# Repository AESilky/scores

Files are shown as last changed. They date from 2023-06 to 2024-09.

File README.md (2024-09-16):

# Score Board

Two team score board w/remote for use in the yard when playing different games
like ladder-ball, cornhole, horseshoes, basketball, etc.

Options for two display types:

1. 2 Digits each for Team-A, Team-B, and a third for Period, Time, etc., and 4 indicators for each team.
2. 2 Linear rows of 24 dots each (for Team-A and Team-B), and 4 indicators for each team.

The Digits type is a typical score board that you would use for baseball,
basketball, football, etc. The Linear display is appropriate for games that
go from 0 to some number of points (maximum of 24), like cornhole, ladderball,
horseshoes, etc.

It uses either a remote or switch banks to control the score. It can use the
remote alone, or with a switch bank, or with two switch banks (without the remote).
The switch banks have either 4 or 6 switches. When using two switch banks, there
is a bank for each team that allow increasing/decreasing the score, resetting to
a lower score (typically 11) and to zero.

The board has a Zigby receiver for non line of sight, communication (though not
yet supported).

The board uses multiplexed 7 segment LED displays to provide a two team/player
two digit score, plus a two digit number that can count periods, innings,
quarters, etc., or can count down/up time. There are four LEDs under the score
for each side that can be used to indicate timeouts left, substitutions made,
etc.

The linear display is also multiplexed LEDs, using the segment drives.

The board also has a OLED display panel (SPI) that can also display the score (intended
for the back side to assist a scorekeeper), as well as for use for setup.

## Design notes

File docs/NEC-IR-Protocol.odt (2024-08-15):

The NEC IR transmission protocol uses pulse distance encoding of the message bits. Each pulse burst (mark – RC transmitter ON) is 562.5µs in length, at a carrier frequency of 38kHz (26.3µs). Logical bits are transmitted as follows:

- Logical '0' – a 562.5µs pulse burst followed by a 562.5µs space, with a total transmit time of 1.125ms
- Logical '1' – a 562.5µs pulse burst followed by a 1.6875ms space, with a total transmit time of 2.25ms

When a key is pressed on the remote controller, the message transmitted consists of the following, in order:

- a 9ms leading pulse burst (16 times the pulse burst length used for a logical data bit)
- a 4.5ms space
- the 8-bit address for the receiving device
- the 8-bit logical inverse of the address
- the 8-bit command
- the 8-bit logical inverse of the command
- a final 562.5µs pulse burst to signify the end of message transmission.

The four bytes of data bits are each sent least significant bit first. Figure 1 illustrates the format of an NEC IR transmission frame, for an address of 00h (00000000b) and a command of ADh (10101101b).

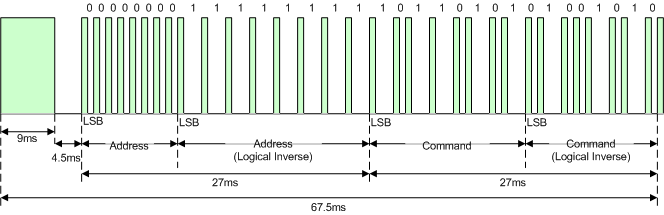
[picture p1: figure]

Figure 1. Example message frame using the NEC IR transmission protocol.

Notice from Figure 1 that it takes:

- 27ms to transmit both the 16 bits for the address (address + inverse) and the 16 bits for the command (command + inverse). This comes from each of the 16 bit blocks ultimately containing eight '0's and eight '1's - giving (8 * 1.125ms) + (8 * 2.25ms).
- 67.5ms to fully transmit the message frame (discounting the final 562.5µs pulse burst that signifies the end of message).

## Repeat Codes

If the key on the remote controller is kept depressed, a repeat code will be issued, typically around 40ms after the pulse burst that signified the end of the message. A repeat code will continue to be sent out at 108ms intervals, until the key is finally released. The repeat code consists of the following, in order:

- a 9ms leading pulse burst
- a 2.25ms space
- a 562.5µs pulse burst to mark the end of the space (and hence end of the transmitted repeat code).

Figure 2 illustrates the transmission of two repeat codes after an initial message frame is sent.

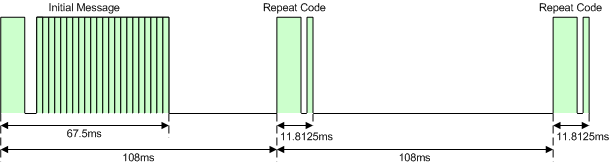
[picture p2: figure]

Figure 2. Example repeat codes sent for a key held down on the transmitting remote controller.

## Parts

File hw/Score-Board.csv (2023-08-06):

Source: | C:\Users\aesil\proj\scores\scores\hw\Score-Board.kicad_sch
Date: | 8/5/2023 7:06:16 PM
Tool: | Eeschema 7.0.2
Generator: | C:\Program Files\KiCad\7.0\bin\scripting\plugins/bom_csv_grouped_by_value_with_fp.py
Component Count: | 95
Ref | Qnty | Value | Cmp name | Footprint | Description | Vendor | DNP
BZ1 | 1 | Buzzer | Buzzer | Buzzer_Beeper:Buzzer_12x9.5RM7.6 | Buzzer, polarized
C1 | 1 | 10uF | C_Polarized_US | Capacitor_THT:CP_Radial_D8.0mm_P3.50mm | Polarized capacitor, US symbol
C2, C3 | 2 | 1.0uF | C | Capacitor_THT:CP_Radial_D5.0mm_P2.00mm | Unpolarized capacitor
C4, C5 | 2 | 0.1uF | C_Small | Capacitor_THT:C_Disc_D5.0mm_W2.5mm_P2.50mm | Unpolarized capacitor, small symbol
Conn1 | 1 | Conn_02x09_Odd_Even | Conn_02x09_Odd_Even | Connector_PinHeader_2.54mm:PinHeader_2x09_P2.54mm_Vertical | Generic connector, double row, 02x09, odd/even pin numbering scheme (row 1 odd numbers, row 2 even numbers), script generated (kicad-library-utils/schlib/autogen/connector/)
D1 | 1 | 1N4004 | 1N4004 | Diode_THT:D_DO-41_SOD81_P10.16mm_Horizontal | 400V 1A General Purpose Rectifier Diode, DO-41
D2, D4 | 2 | D_Schottky_PP | Schottky_Diode_PWR_Protect_AES | Diode_THT:D_DO-35_SOD27_P10.16mm_Horizontal | Schottky diode - Small Reverse Power Protection
D3 | 1 | D_Schottky | D_Schottky | Diode_THT:D_DO-35_SOD27_P10.16mm_Horizontal | Schottky diode
H1, H2, H3, H4, H5, H6 | 6 | MountingHole | MountingHole | MountingHole:MountingHole_3.2mm_M3 | Mounting Hole without connection
IR1, IR2 | 2 | TSOP382xx | TSOP382xx | OptoDevice:Vishay_MINICAST-3Pin | Photo Modules for PCM Remote Control Systems
J1 | 1 | Barrel_Jack | Barrel_Jack | AES_Library:CUI_PJ-037B | DC Barrel Jack
J2 | 1 | Screw_Terminal_01x02 | Screw_Terminal_01x02 | TerminalBlock_Philmore:TerminalBlock_Philmore_TB132_1x02_P5.00mm_Horizontal | Generic screw terminal, single row, 01x02, script generated (kicad-library-utils/schlib/autogen/connector/)
J3 | 1 | SPI-Disp | Conn_01x07 | Connector_PinSocket_2.54mm:PinSocket_1x07_P2.54mm_Vertical | Generic connector, single row, 01x07, script generated (kicad-library-utils/schlib/autogen/connector/)
J4 | 1 | Conn_01x03 | Conn_01x03 | Connector_PinHeader_2.54mm:PinHeader_1x03_P2.54mm_Vertical | Generic connector, single row, 01x03, script generated (kicad-library-utils/schlib/autogen/connector/)
J5 | 1 | Conn_01x04 | Conn_01x04 | Connector_PinHeader_2.54mm:PinHeader_1x04_P2.54mm_Vertical | Generic connector, single row, 01x04, script generated (kicad-library-utils/schlib/autogen/connector/)
J6 | 1 | J-V3.3 | Conn_01x02 | Connector_PinHeader_2.54mm:PinHeader_1x02_P2.54mm_Vertical | Generic connector, single row, 01x02, script generated (kicad-library-utils/schlib/autogen/connector/)
J7 | 1 | J-V12 | Conn_01x02 | Connector_PinHeader_2.54mm:PinHeader_1x02_P2.54mm_Vertical | Generic connector, single row, 01x02, script generated (kicad-library-utils/schlib/autogen/connector/)
J8 | 1 | J-VSYS | Conn_01x02 | Connector_PinHeader_2.54mm:PinHeader_1x02_P2.54mm_Vertical | Generic connector, single row, 01x02, script generated (kicad-library-utils/schlib/autogen/connector/)
LED1 | 1 | PWR | LED | LED_THT:LED_D5.0mm | Light emitting diode
LED2 | 1 | ZBRUN | LED | LED_THT:LED_D5.0mm | Light emitting diode
LED3 | 1 | ZBNWRK | LED | LED_THT:LED_D5.0mm | Light emitting diode
Q1, Q2, Q3, Q4, Q5, Q6, Q7, Q15, Q16, Q17, Q18, Q19, Q20, Q21, Q22 | 15 | 2N3904 | 2N3904 | Package_TO_SOT_THT:TO-92_Inline | 0.2A Ic, 40V Vce, Small Signal NPN Transistor, TO-92
Q8, Q9, Q10, Q11, Q12, Q13, Q14 | 7 | 2N3905 | 2N3905 | Package_TO_SOT_THT:TO-92_Inline | -0.2A Ic, -40V Vce, Small Signal PNP Transistor, TO-92
R1, R2, R3, R4, R5 | 5 | 150 | R_Small_US | Resistor_THT:R_Axial_DIN0207_L6.3mm_D2.5mm_P10.16mm_Horizontal | Resistor, small US symbol
R6, R8, R10, R12, R14, R16, R18 | 7 | 1k | R_Small_US | Resistor_THT:R_Axial_DIN0207_L6.3mm_D2.5mm_P10.16mm_Horizontal | Resistor, small US symbol
R7, R9, R11, R13, R15, R17, R19 | 7 | 270 | R_Small_US | Resistor_THT:R_Axial_DIN0207_L6.3mm_D2.5mm_P10.16mm_Horizontal | Resistor, small US symbol
R20, R33, R34, R39, R40, R41, R42, R43 | 8 | 47 | R_Small_US | Resistor_THT:R_Axial_DIN0207_L6.3mm_D2.5mm_P10.16mm_Horizontal | Resistor, small US symbol
R21, R22, R23, R24, R25, R26, R27, R28 | 8 | 10k | R_Small_US | Resistor_THT:R_Axial_DIN0207_L6.3mm_D2.5mm_P10.16mm_Horizontal | Resistor, small US symbol
SD1 | 1 | MicroSD-Socket | Micro_SD_Card_Det1 | AES_Library:SDCard-GCT_MEM2075-00-140-01-A | Micro SD Card Socket with one card detection pin
SW1 | 1 | RESET | SW_Push | AES_Library:SW_TL1100F160Q | Push button switch, generic, two pins
SW2 | 1 | NETWORK | SW_Push | AES_Library:SW_TL1100F160Q | Push button switch, generic, two pins
SW3 | 1 | INPUT-SW | SW_Push | AES_Library:SW_TL1100F160Q | Push button switch, generic, two pins
TP1 | 1 | Conn_01x01 | Conn_01x01 | Connector_PinHeader_2.54mm:PinHeader_1x01_P2.54mm_Vertical | Generic connector, single row, 01x01, script generated (kicad-library-utils/schlib/autogen/connector/)
U1 | 1 | PicoW | PicoW | AES_Library:RPi_PicoW_SMD_TH
U2 | 1 | E18-MS1-PCB | E18-MS1-PCB | AES_Library:E18-MS1-PCB-AES | EBYTE ZigBee 3.0 E18 Command Module
U5 | 1 | MCP1702-5002E | MCP1700x-500xxTO | Package_TO_SOT_THT:TO-92_Inline | 250mA Low Quiscent Current LDO, 5.0V output, TO-92

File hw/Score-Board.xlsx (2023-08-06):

Source: | C:\Users\aesil\proj\scores\scores\hw\Score-Board.kicad_sch
Date: | 2023-08-05 19:06
Tool: | Eeschema 7.0.2
Generator: | C:\Program Files\KiCad\7.0\bin\scripting\plugins/bom_csv_grouped_by_value_with_fp.py
Component Count: | 95
Ref | Qnty | Value | Cmp name | Description | DNP
BZ1 | 1 | Buzzer | Buzzer | Buzzer, polarized
C1 | 1 | 10uF | C_Polarized_US | Polarized capacitor, US symbol
C2, C3 | 2 | 1.0uF | C | Unpolarized capacitor
C4, C5 | 2 | 0.1uF | C_Small | Unpolarized capacitor, small symbol
Conn1 | 1 | Conn_02x09_Odd_Even | Conn_02x09_Odd_Even | Generic connector, double row, 02x09, odd/even pin numbering
D1 | 1 | 1N4004 | 1N4004 | 400V 1A General Purpose Rectifier Diode, DO-41
D2, D4 | 2 | D_Schottky_PP | Schottky_Diode_PWR_Protect_AES | Schottky diode - Small Reverse Power Protection
D3 | 1 | D_Schottky | D_Schottky | Schottky diode
H1, H2, H3, H4, H5, H6 | 6 | MountingHole | MountingHole | Mounting Hole without connection
IR1, IR2 | 2 | TSOP382xx | TSOP382xx | Photo Modules for PCM Remote Control Systems
J1 | 1 | Barrel_Jack | Barrel_Jack | DC Barrel Jack
J2 | 1 | Screw_Terminal_01x02 | Screw_Terminal_01x02 | Generic screw terminal, single row, 01x02
J3 | 1 | SPI-Disp | Conn_01x07 | Generic connector, single row, 01x07
J4 | 1 | Conn_01x03 | Conn_01x03 | Generic connector, single row, 01x03
J5 | 1 | Conn_01x04 | Conn_01x04 | Generic connector, single row, 01x04
J6 | 1 | J-V3.3 | Conn_01x02 | Generic connector, single row, 01x02
J7 | 1 | J-V12 | Conn_01x02 | Generic connector, single row, 01x02
J8 | 1 | J-VSYS | Conn_01x02 | Generic connector, single row, 01x02
LED1 | 1 | PWR | LED | Light emitting diode
LED2 | 1 | ZBRUN | LED | Light emitting diode
LED3 | 1 | ZBNWRK | LED | Light emitting diode
Q1, Q2, Q3, Q4, Q5, Q6, Q7, Q15, Q16, Q17, Q18, Q19, Q20, Q21, Q22 | 15 | 2N3904 | 2N3904 | 0.2A Ic, 40V Vce, Small Signal NPN Transistor, TO-92
Q8, Q9, Q10, Q11, Q12, Q13, Q14 | 7 | 2N3905 | 2N3905 | -0.2A Ic, -40V Vce, Small Signal PNP Transistor, TO-92
R1, R2, R3, R4, R5 | 5 | 150 | R_Small_US | Resistor, small US symbol
R6, R8, R10, R12, R14, R16, R18 | 7 | 1k | R_Small_US | Resistor, small US symbol
R7, R9, R11, R13, R15, R17, R19 | 7 | 270 | R_Small_US | Resistor, small US symbol
R20, R33, R34, R39, R40, R41, R42, R43 | 8 | 47 | R_Small_US | Resistor, small US symbol
R21, R22, R23, R24, R25, R26, R27, R28 | 8 | 10k | R_Small_US | Resistor, small US symbol
SD1 | 1 | MicroSD-Socket | Micro_SD_Card_Det1 | Micro SD Card Socket with one card detection pin
SW1 | 1 | RESET | SW_Push | Push button switch, generic, two pins
SW2 | 1 | NETWORK | SW_Push | Push button switch, generic, two pins
SW3 | 1 | INPUT-SW | SW_Push | Push button switch, generic, two pins
TP1 | 1 | Conn_01x01 | Conn_01x01 | Generic connector, single row, 01x01
U1 | 1 | PicoW | PicoW
U2 | 1 | E18-MS1-PCB | E18-MS1-PCB | EBYTE ZigBee 3.0 E18 Command Module
U5 | 1 | MCP1702-5002E | MCP1700x-500xxTO | 250mA Low Quiscent Current LDO, 5.0V output, TO-92

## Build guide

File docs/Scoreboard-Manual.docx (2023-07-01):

Silky Portable Scoreboard w/Remote

Cover page
back

No page number

# About the Silky Scoreboard

The Silky Scoreboard w/Remote (SSwR) is a portable, two team/player scoreboard with an Infrared and radio (ZigBee) wireless remote. The scoreboard has multiple modes tailored to keeping score for a variety of common games.

First numbered even page

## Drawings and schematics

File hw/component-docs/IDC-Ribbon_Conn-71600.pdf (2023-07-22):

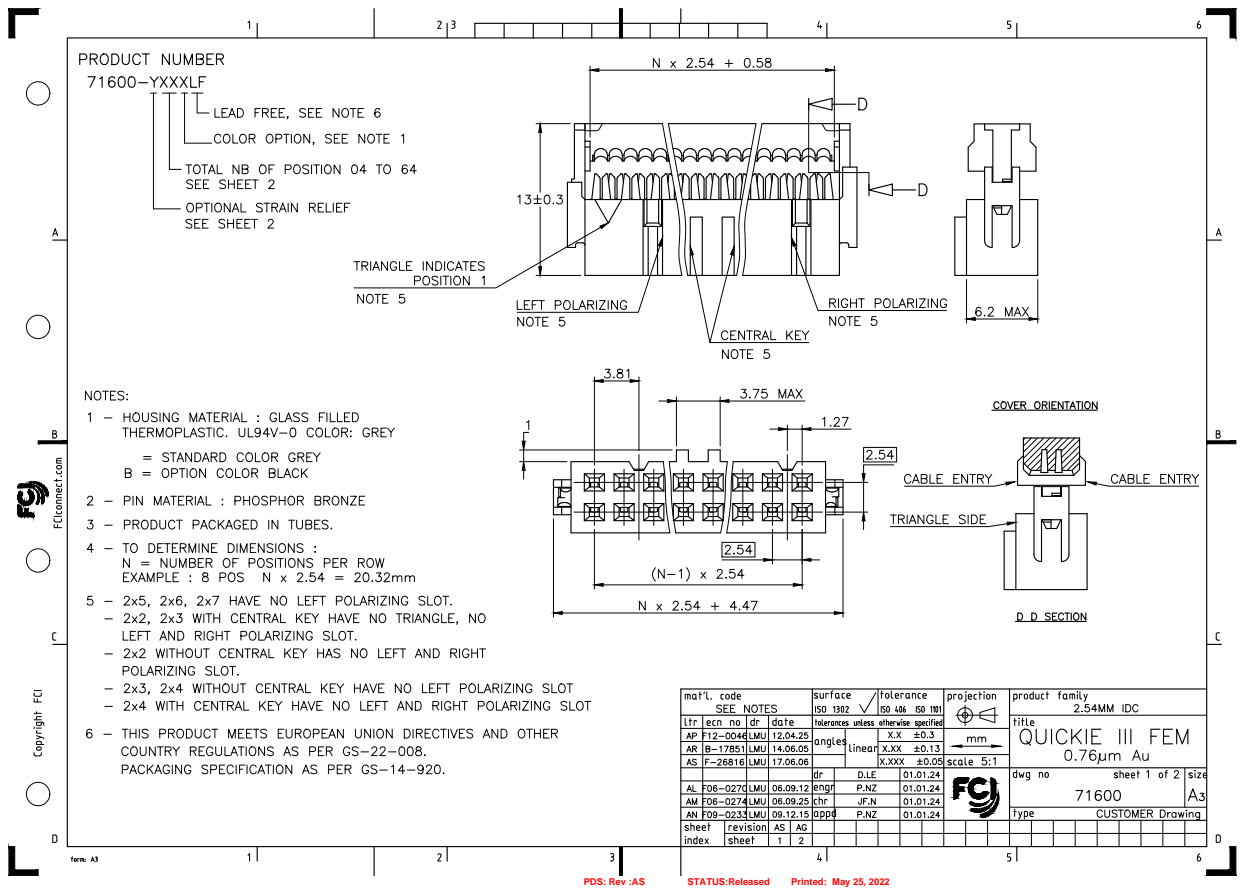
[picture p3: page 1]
PDS: Rev :AS; STATUS:Released; Printed: May 25, 2022

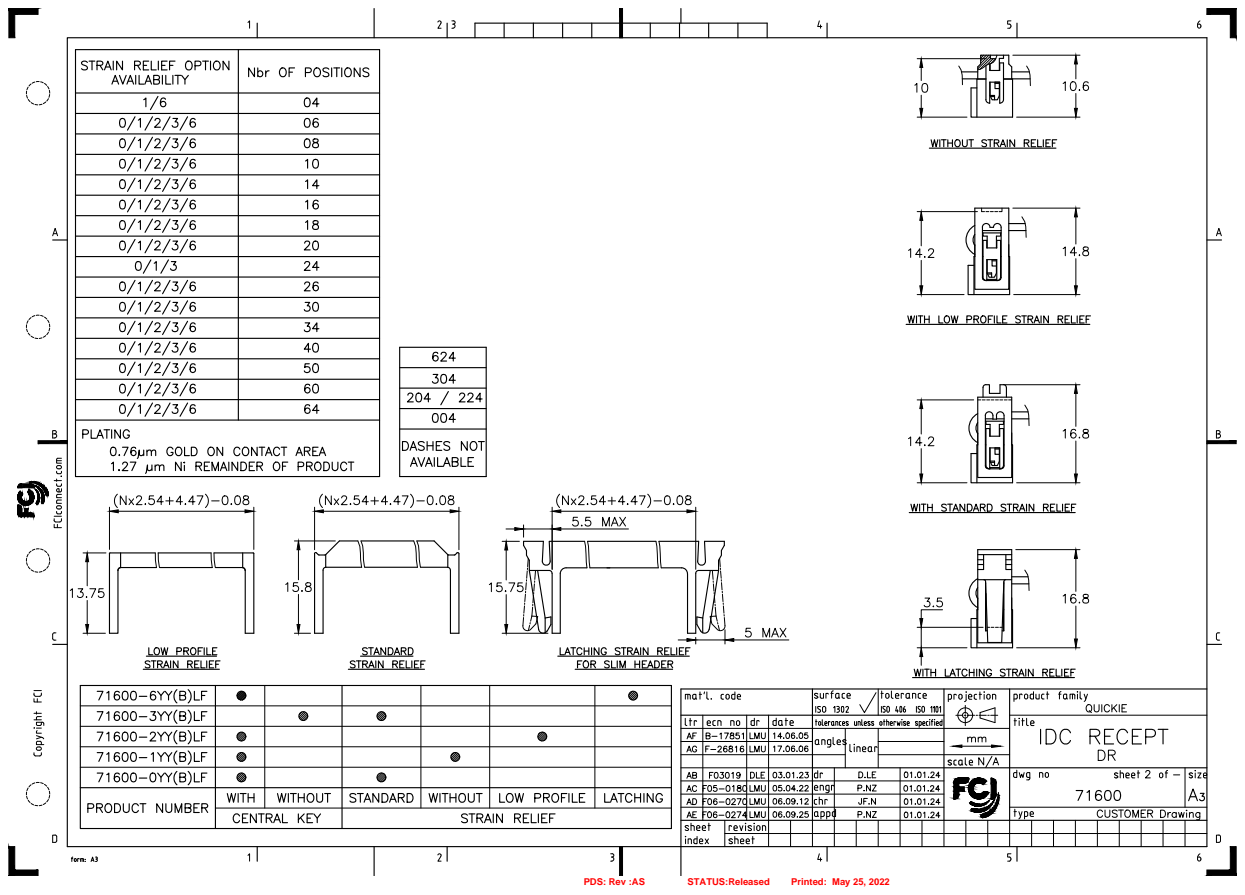
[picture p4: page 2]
PDS: Rev :AS; STATUS:Released; Printed: May 25, 2022

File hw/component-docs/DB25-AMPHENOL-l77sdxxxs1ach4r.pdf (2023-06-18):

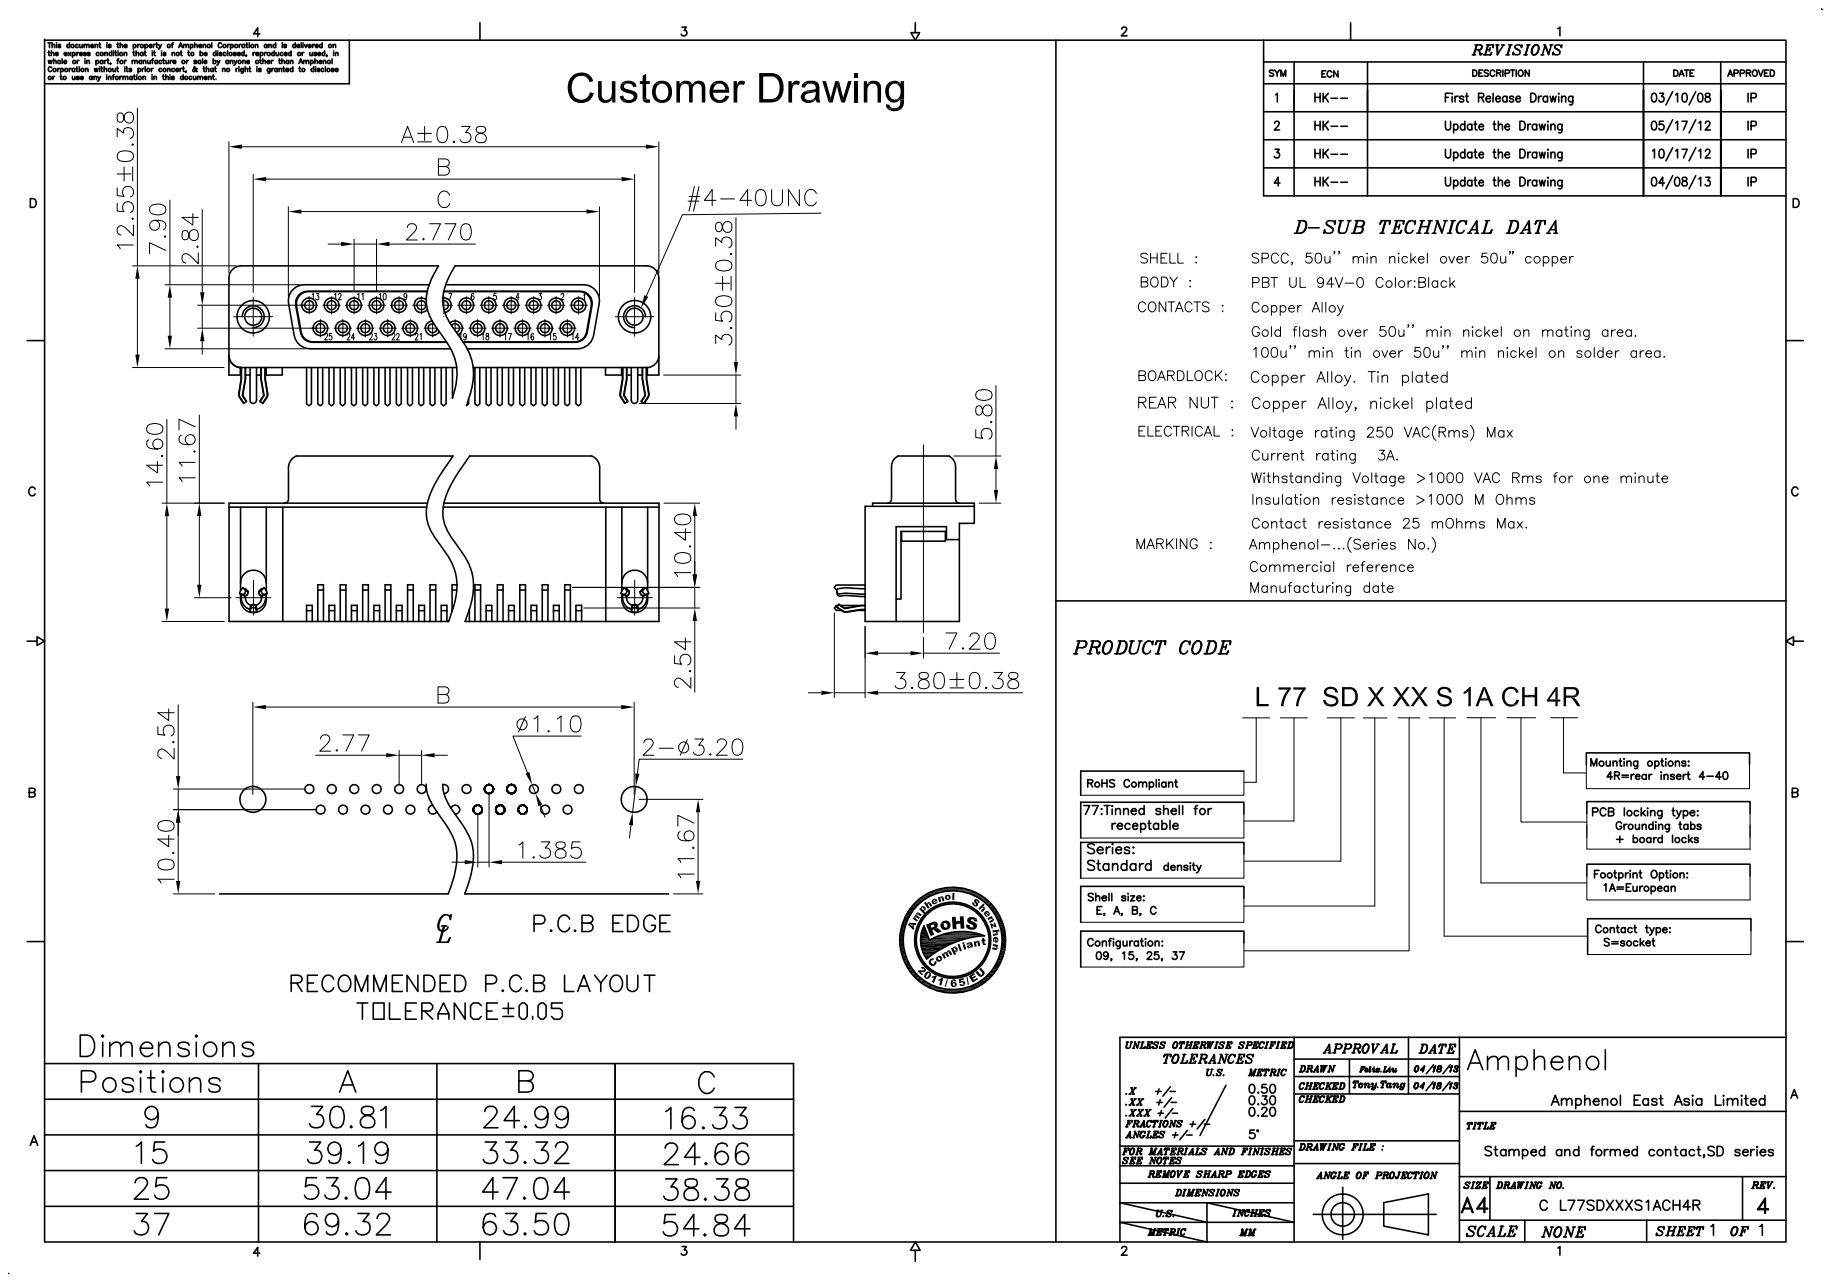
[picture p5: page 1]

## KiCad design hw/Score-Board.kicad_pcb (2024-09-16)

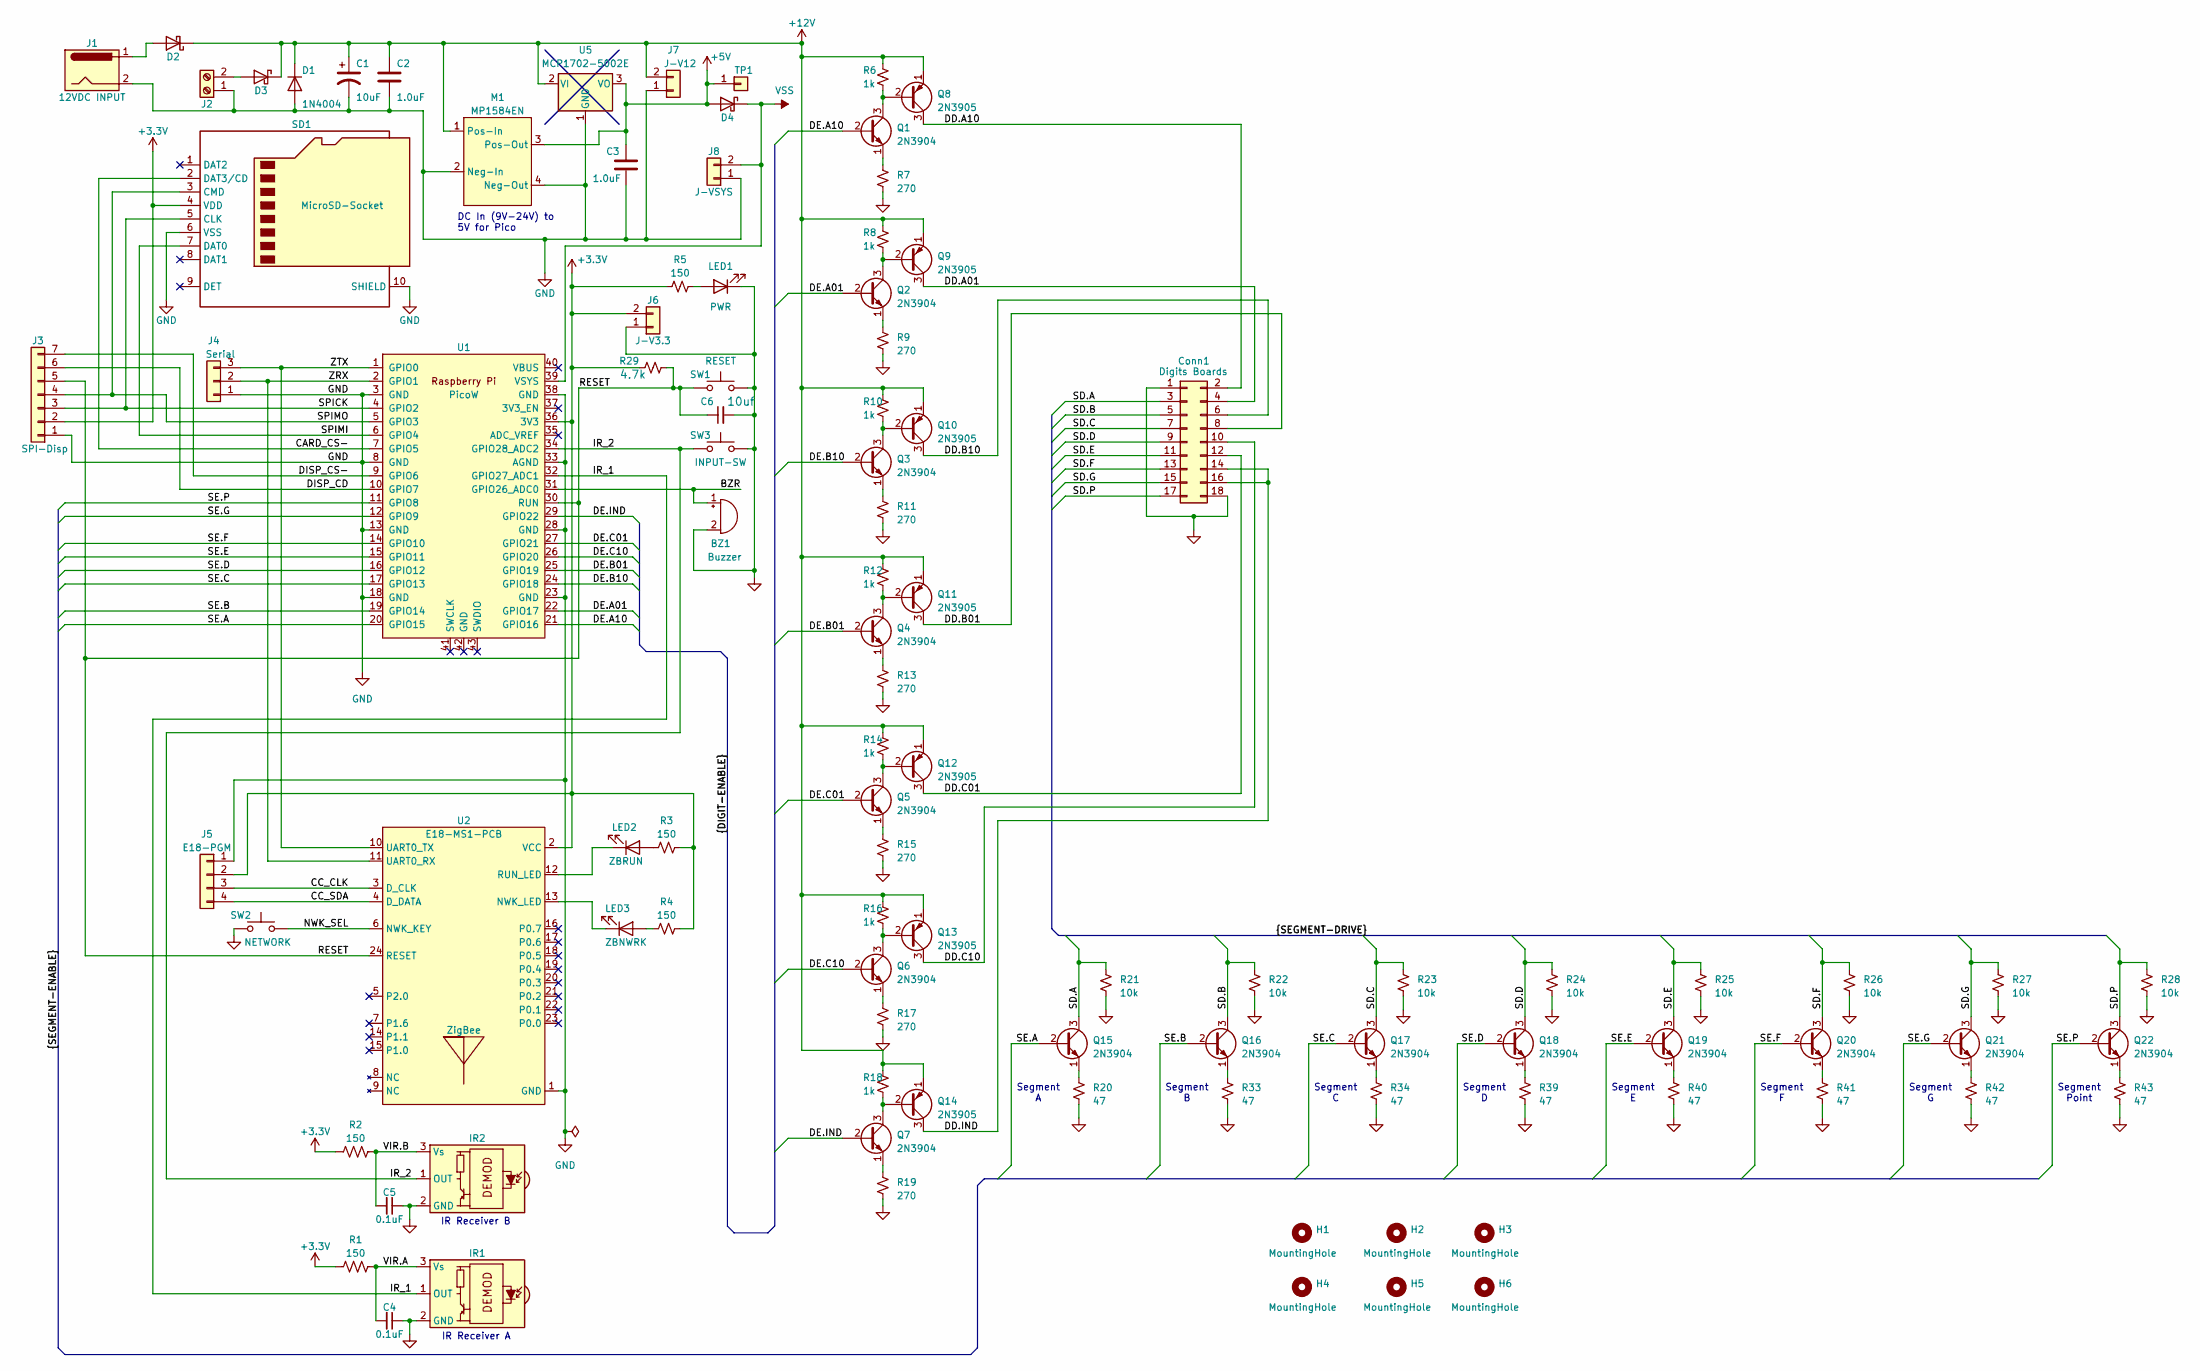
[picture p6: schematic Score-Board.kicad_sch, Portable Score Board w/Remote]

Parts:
BZ1: Buzzer; Buzzer_12x9.5RM7.6
C1: 10uF; CP_Radial_D8.0mm_P3.50mm
C2, C3: 1.0uF; CP_Radial_D5.0mm_P2.00mm
C4, C5: 0.1uF; C_Disc_D5.0mm_W2.5mm_P2.50mm
C6: 10uf
Conn1: Conn_02x09_Odd_Even; PinHeader_2x09_P2.54mm_Vertical
D1: 1N4004; D_DO-41_SOD81_P10.16mm_Horizontal
D2, D4: D_Schottky_PP; D_DO-35_SOD27_P10.16mm_Horizontal
D3: D_Schottky; D_DO-35_SOD27_P10.16mm_Horizontal
H1, H2, H3, H4, H5, H6: MountingHole; MountingHole_3.2mm_M3
IR1, IR2: TSOP382xx; Vishay_MINICAST-3Pin
J1: Barrel_Jack; CUI_PJ-037B
J2: Screw_Terminal_01x02; TerminalBlock_Philmore_TB132_1x02_P5.00mm_Horizontal
J3: SPI-Disp; PinSocket_1x07_P2.54mm_Vertical
J4: Conn_01x03; PinHeader_1x03_P2.54mm_Vertical
J5: Conn_01x04; PinHeader_1x04_P2.54mm_Vertical
J6: J-V3.3; PinHeader_1x02_P2.54mm_Vertical
J7: J-V12; PinHeader_1x02_P2.54mm_Vertical
J8: J-VSYS; PinHeader_1x02_P2.54mm_Vertical
LED1: PWR; LED_D5.0mm
LED2: ZBRUN; LED_D5.0mm
LED3: ZBNWRK; LED_D5.0mm
M1: MP1584EN
Q1, Q2, Q3, Q4, Q5, Q6, Q7, Q15, Q16, Q17, Q18, Q19, Q20, Q21, Q22: 2N3904; TO-92_Inline
Q8, Q9, Q10, Q11, Q12, Q13, Q14: 2N3905; TO-92_Inline
R1, R2, R3, R4, R5: 150; R_Axial_DIN0207_L6.3mm_D2.5mm_P10.16mm_Horizontal
R6, R8, R10, R12, R14, R16, R18: 1k; R_Axial_DIN0207_L6.3mm_D2.5mm_P10.16mm_Horizontal
R7, R9, R11, R13, R15, R17, R19: 270; R_Axial_DIN0207_L6.3mm_D2.5mm_P10.16mm_Horizontal
R20, R33, R34, R39, R40, R41, R42, R43: 47; R_Axial_DIN0207_L6.3mm_D2.5mm_P10.16mm_Horizontal
R21, R22, R23, R24, R25, R26, R27, R28: 10k; R_Axial_DIN0207_L6.3mm_D2.5mm_P10.16mm_Horizontal
R29: 4.7k; R_Axial_DIN0207_L6.3mm_D2.5mm_P10.16mm_Horizontal
SD1: MicroSD-Socket; SDCard-GCT_MEM2075-00-140-01-A
SW1: RESET; SW_TL1100F160Q
SW2: NETWORK; SW_TL1100F160Q
SW3: INPUT-SW; SW_TL1100F160Q
TP1: Conn_01x01; PinHeader_1x01_P2.54mm_Vertical
U1: PicoW; RPi_PicoW_SMD_TH
U2: E18-MS1-PCB; E18-MS1-PCB-AES
U5: MCP1702-5002E; TO-92_Inline

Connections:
+3.3V: J3.2, J5.2, J6.2, R1.1 (I), R2.1 (I), R3.2, R4.2, R5.1, R29.1, SD1.4 (VDD), U1.36 (3V3), U2.2 (VCC)
+5V: C3.1, D4.2 (A), M1.3 (Pos-Out), TP1.1, U5.3 (VO)
+12V: C1.1, C2.1, D1.1 (K), D2.1 (K), D3.1 (K), J7.2, M1.1 (Pos-In), Q8.1 (E), Q9.1 (E), Q10.1 (E), Q11.1 (E), Q12.1 (E), Q13.1 (E), Q14.1 (E), R6.1, R8.1, R10.1, R12.1, R14.1, R16.1, R18.1, U5.2 (VI)
/BZR: BZ1.1 (-), U1.31 (GPIO26_ADC0)
/CARD_CS-: SD1.2 (DAT3/CD), U1.7 (GPIO5)
/CC_CLK: J5.3, U2.3 (D_CLK)
/CC_SDA: J5.4, U2.4 (D_DATA)
/DD.A01: Conn1.4, Q9.3 (C)
/DD.A10: Conn1.2, Q8.3 (C)
/DD.B01: Conn1.8, Q11.3 (C)
/DD.B10: Conn1.6, Q10.3 (C)
/DD.C01: Conn1.12, Q12.3 (C)
/DD.C10: Conn1.10, Q13.3 (C)
/DD.IND: Conn1.14, Conn1.16, Q14.3 (C)
/DE.A01: Q2.2 (B), U1.22 (GPIO17)
/DE.A10: Q1.2 (B), U1.21 (GPIO16)
/DE.B01: Q4.2 (B), U1.25 (GPIO19)
/DE.B10: Q3.2 (B), U1.24 (GPIO18)
/DE.C01: Q5.2 (B), U1.27 (GPIO21)
/DE.C10: Q6.2 (B), U1.26 (GPIO20)
/DE.IND: Q7.2 (B), U1.29 (GPIO22)
/DISP_CD: J3.6, U1.10 (GPIO7)
/DISP_CS-: J3.7, U1.9 (GPIO6)
/IR_1: IR1.1 (OUT), U1.32 (GPIO27_ADC1)
/IR_2: IR2.1 (OUT), SW3.1, U1.34 (GPIO28_ADC2)
/NWK_SEL: SW2.2, U2.6 (NWK_KEY)
/RESET: C6.1, J3.5, R29.2, SW1.1, U1.30 (RUN), U2.24 (RESET)
/SD.A: Conn1.3, Q15.3 (C), R21.1
/SD.B: Conn1.5, Q16.3 (C), R22.1
/SD.C: Conn1.7, Q17.3 (C), R23.1
/SD.D: Conn1.9, Q18.3 (C), R24.1
/SD.E: Conn1.11, Q19.3 (C), R25.1
/SD.F: Conn1.13, Q20.3 (C), R26.1
/SD.G: Conn1.15, Q21.3 (C), R27.1
/SD.P: Conn1.17, Q22.3 (C), R28.1
/SE.A: Q15.2 (B), U1.20 (GPIO15)
/SE.B: Q16.2 (B), U1.19 (GPIO14)
/SE.C: Q17.2 (B), U1.17 (GPIO13)
/SE.D: Q18.2 (B), U1.16 (GPIO12)
/SE.E: Q19.2 (B), U1.15 (GPIO11)
/SE.F: Q20.2 (B), U1.14 (GPIO10)
/SE.G: Q21.2 (B), U1.12 (GPIO9)
/SE.P: Q22.2 (B), U1.11 (GPIO8)
/SPICK: J3.3, SD1.5 (CLK), U1.4 (GPIO2)
/SPIMI: SD1.7 (DAT0), U1.6 (GPIO4)
/SPIMO: J3.4, SD1.3 (CMD), U1.5 (GPIO3)
/VIR.A: C4.2, IR1.3 (Vs), R1.2 (O)
/VIR.B: C5.2, IR2.3 (Vs), R2.2 (O)
/ZRX: J4.2, U1.2 (GPIO1), U2.11 (UART0_RX)
/ZTX: J4.3, U1.1 (GPIO0), U2.10 (UART0_TX)
GND: BZ1.2 (+), C1.2, C2.2, C3.2, C4.1, C5.1, C6.2, Conn1.1, Conn1.18, D1.2 (A), IR1.2 (GND), IR2.2 (GND), J1.2, J2.1, J3.1, J4.1, J5.1, J6.1, J7.1, J8.1, LED1.1 (K), M1.2 (Neg-In), M1.4 (Neg-Out), R7.2, R9.2, R11.2, R13.2, R15.2, R17.2, R19.2, R20.2, R21.2, R22.2, R23.2, R24.2, R25.2, R26.2, R27.2, R28.2, R33.2, R34.2, R39.2, R40.2, R41.2, R42.2, R43.2, SD1.6 (VSS), SD1.10 (SHIELD), SW1.2, SW2.1, SW3.2, U1.3 (GND), U1.8 (GND), U1.13 (GND), U1.18 (GND), U1.23 (GND), U1.28 (GND), U1.33 (AGND), U1.38 (GND), U2.1 (GND), U5.1 (GND)
unnamed: D2.2 (A), J1.1
unnamed: D3.2 (A), J2.2
unnamed: LED1.2 (A), R5.2
unnamed: LED2.2 (A), R3.1
unnamed: LED2.1 (K), U2.12 (RUN_LED)
unnamed: LED3.2 (A), R4.1
unnamed: LED3.1 (K), U2.13 (NWK_LED)
unnamed: Q1.3 (C), Q8.2 (B), R6.2
unnamed: Q1.1 (E), R7.1
unnamed: Q2.3 (C), Q9.2 (B), R8.2
unnamed: Q2.1 (E), R9.1
unnamed: Q3.1 (E), R11.1
unnamed: Q4.1 (E), R13.1
unnamed: Q5.1 (E), R15.1
unnamed: Q6.1 (E), R17.1
unnamed: Q7.1 (E), R19.1
unnamed: Q3.3 (C), Q10.2 (B), R10.2
unnamed: Q4.3 (C), Q11.2 (B), R12.2
unnamed: Q5.3 (C), Q12.2 (B), R14.2
unnamed: Q6.3 (C), Q13.2 (B), R16.2
unnamed: Q7.3 (C), Q14.2 (B), R18.2
unnamed: Q15.1 (E), R20.1
unnamed: Q16.1 (E), R33.1
unnamed: Q17.1 (E), R34.1
unnamed: Q18.1 (E), R39.1
unnamed: Q19.1 (E), R40.1
unnamed: Q20.1 (E), R41.1
unnamed: Q21.1 (E), R42.1
unnamed: Q22.1 (E), R43.1
VSS: D4.1 (K), J8.2, U1.39 (VSYS)

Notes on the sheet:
Segment E
Segment C
Segment B
Segment D
Segment G
Segment A
Segment F
Segment Point
IR Receiver B
DC In (9V-24V) to 5V for Pico
IR Receiver A

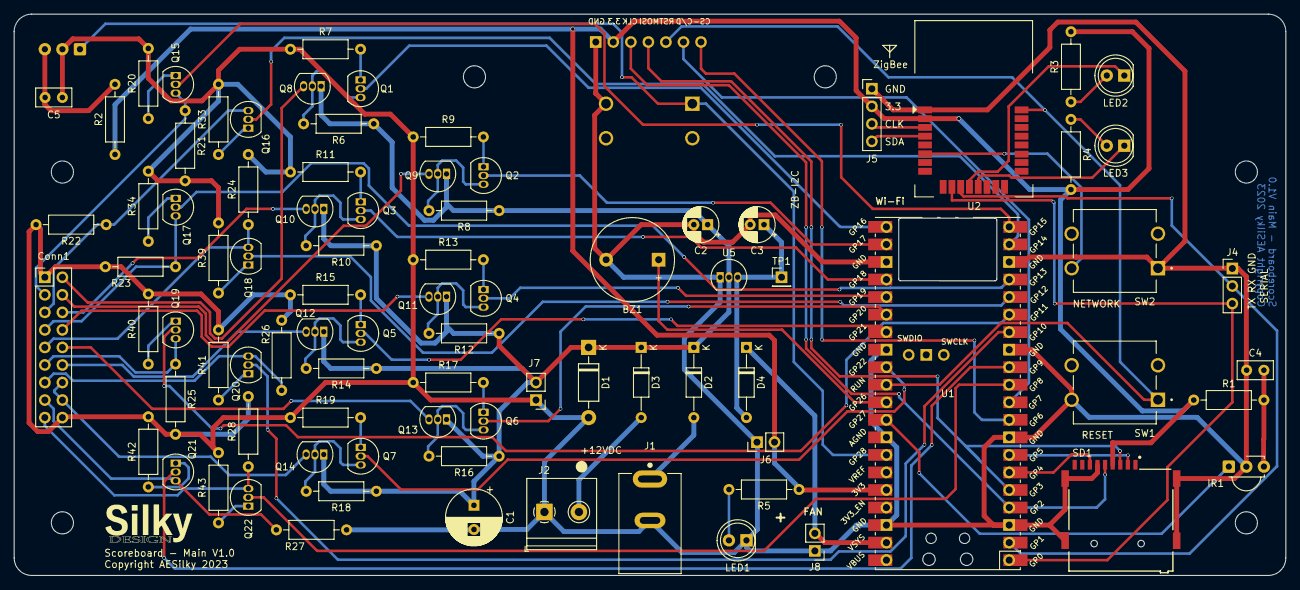
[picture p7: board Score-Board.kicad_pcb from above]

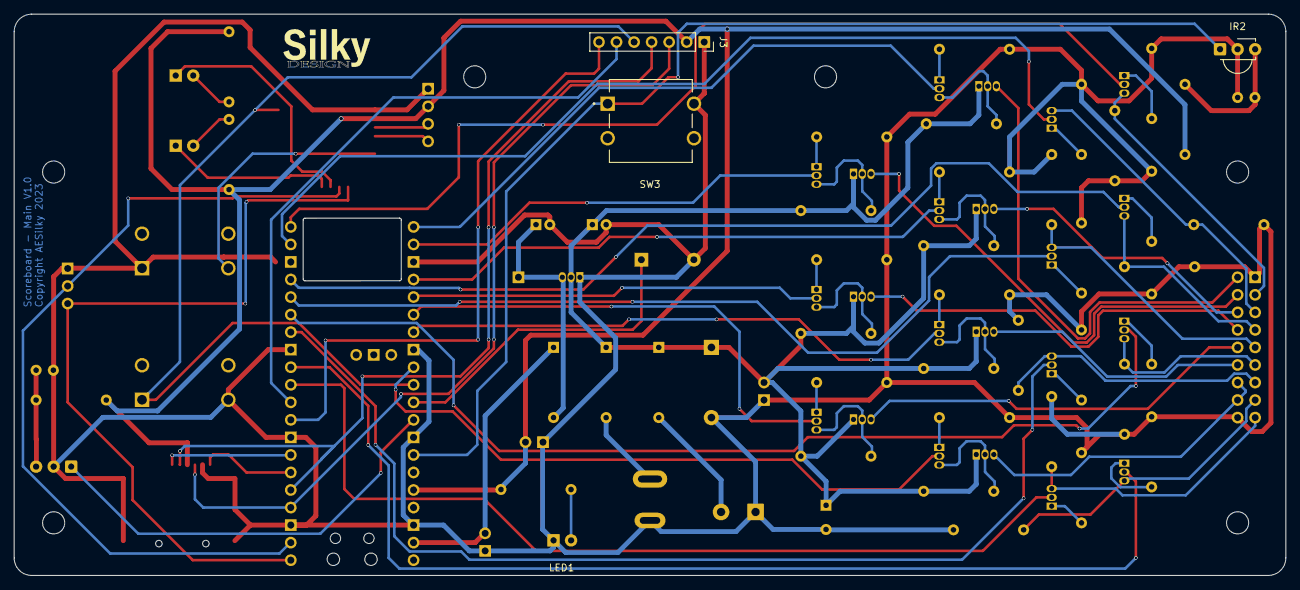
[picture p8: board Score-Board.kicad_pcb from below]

Board: 2 copper layers, 184.2 x 81.3 mm, 95 parts (3 on the bottom side), 81 nets.

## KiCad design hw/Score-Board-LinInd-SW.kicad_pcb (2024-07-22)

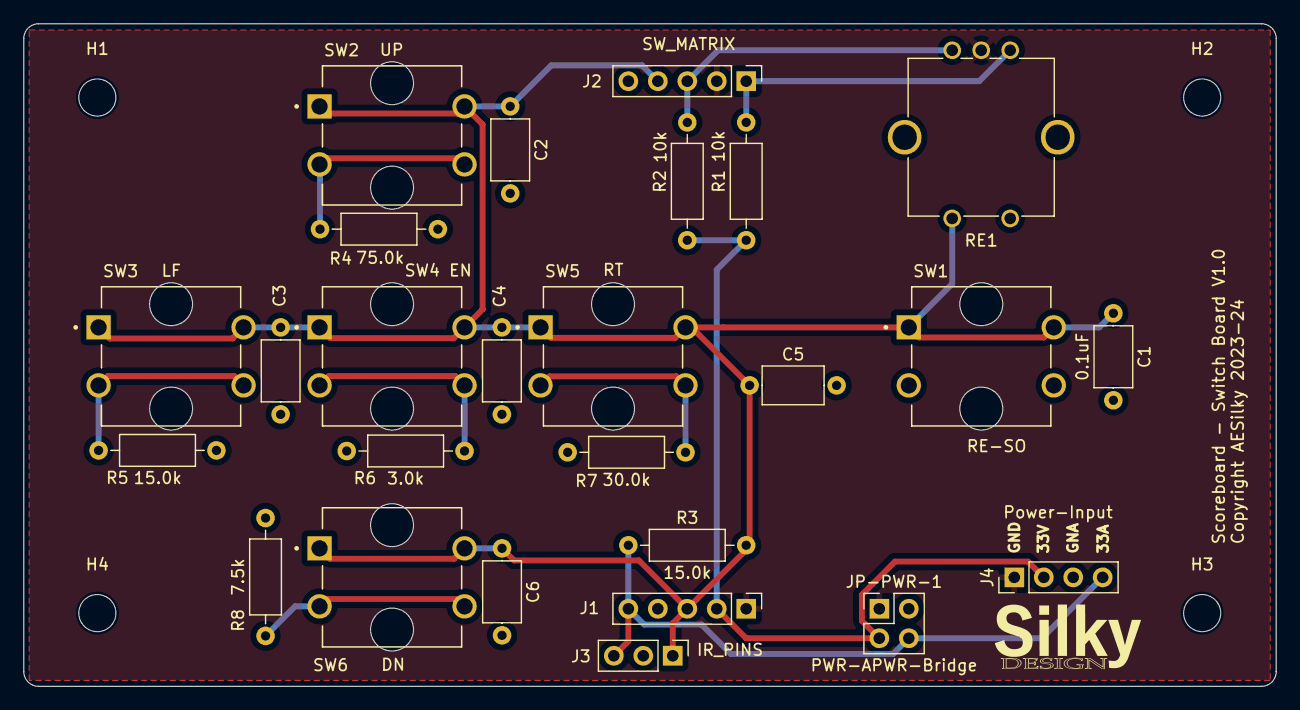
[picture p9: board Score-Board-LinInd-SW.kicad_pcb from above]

Board: 2 copper layers, 108.0 x 57.1 mm, 31 parts (0 on the bottom side), 12 nets.

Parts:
C1, C2, C3, C4, C5, C6: 0.1uF; C_Axial_L5.1mm_D3.1mm_P7.50mm_Horizontal
G1: LOGO; SILKY-DESIGN-logo-0_50-AES
H1, H2, H3, H4: MountingHole; MountingHole_3.2mm_M3
J1: IR_PINS; PinHeader_1x05_P2.54mm_Vertical
J2: SW_MATRIX; PinHeader_1x05_P2.54mm_Vertical
J3: IR_CONN; PinHeader_1x03_P2.54mm_Vertical
J4: Power-Input; PinHeader_1x04_P2.54mm_Vertical
JP-PWR-1: PWR-APWR-Bridge; PinHeader_2x02_P2.54mm_Vertical
R1, R2: 10k; R_Axial_DIN0207_L6.3mm_D2.5mm_P10.16mm_Horizontal
R3, R5: 15.0k; R_Axial_DIN0207_L6.3mm_D2.5mm_P10.16mm_Horizontal
R4: 75.0k; R_Axial_DIN0207_L6.3mm_D2.5mm_P10.16mm_Horizontal
R6: 3.0k; R_Axial_DIN0207_L6.3mm_D2.5mm_P10.16mm_Horizontal
R7: 30.0k; R_Axial_DIN0207_L6.3mm_D2.5mm_P10.16mm_Horizontal
R8: 7.5k; R_Axial_DIN0207_L6.3mm_D2.5mm_P10.16mm_Horizontal
RE1: RotEnc-SW; RotaryEncoder_Bourns_Vertical_PEC12R-3xxxF-Sxxxx
SW1: RE-SO; AES-SW_PUSH_TH_1P1T_12mm
SW2: UP; AES-SW_PUSH_TH_1P1T_12mm
SW3: LF; AES-SW_PUSH_TH_1P1T_12mm
SW4: EN; AES-SW_PUSH_TH_1P1T_12mm
SW5: RT; AES-SW_PUSH_TH_1P1T_12mm
SW6: DN; AES-SW_PUSH_TH_1P1T_12mm

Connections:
+3.3V: J1.2, J4.2, JP-PWR-1.3, R1.1, R2.1
+3.3VA: J1.5, J3.3, J4.4, JP-PWR-1.4, R3.1
/RE_A: J2.1, R1.2, RE1.A
/RE_B: J2.3, R2.2, RE1.B
/SW_MTRX: C1.1, C2.1, C3.1, C4.1, C5.1, C6.1, J1.3, J2.4, J3.1, R3.2, RE1.S2, SW1.1, SW1.2, SW2.1, SW2.2, SW3.1, SW3.2, SW4.1, SW4.2, SW5.1, SW5.2, SW6.1, SW6.2
GND: J1.1, J2.2, J4.1, JP-PWR-1.1, RE1.C
GNDA: C1.2, C2.2, C3.2, C4.2, C5.2, C6.2, J1.4, J2.5, J3.2, J4.3, JP-PWR-1.2, R4.1, R5.1, R6.1, R7.1, R8.1, RE1.S1, SW1.3, SW1.4
unnamed: R4.2, SW2.3, SW2.4
unnamed: R5.2, SW3.3, SW3.4
unnamed: R6.2, SW4.3, SW4.4
unnamed: R7.2, SW5.3, SW5.4
unnamed: R8.2, SW6.3, SW6.4

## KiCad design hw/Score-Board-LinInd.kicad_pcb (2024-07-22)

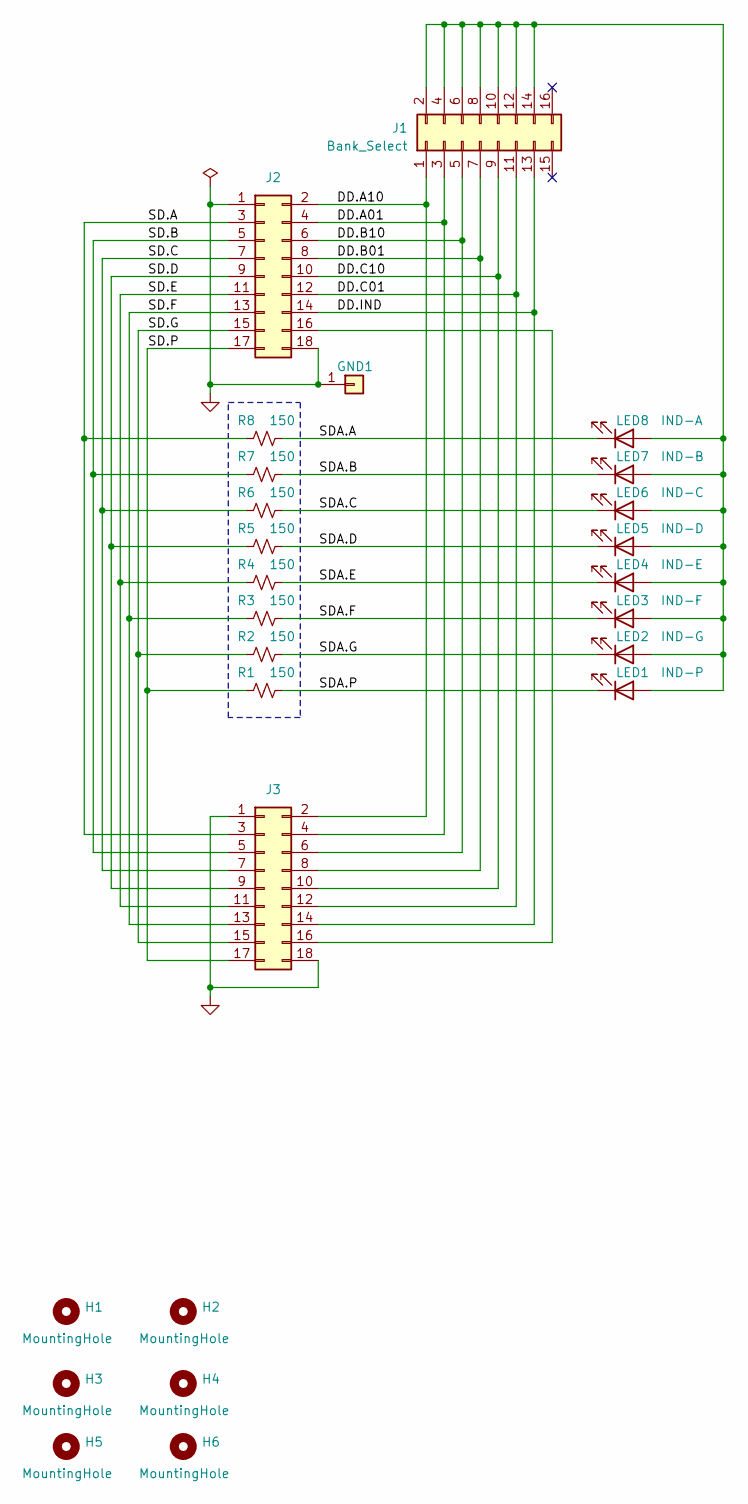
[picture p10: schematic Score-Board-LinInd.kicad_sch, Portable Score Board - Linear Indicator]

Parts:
GND1: Conn_01x01; PinHeader_1x01_P2.54mm_Vertical
H1, H2, H3, H4, H5, H6: MountingHole; MountingHole_3.2mm_M3
J1: Bank_Select; PinHeader_2x08_P2.54mm_Vertical
J2, J3: DigSeg-Drive; PinHeader_2x09_P2.54mm_Vertical
LED1: IND-P; LED_D10.0mm
LED2: IND-G; LED_D10.0mm
LED3: IND-F; LED_D10.0mm
LED4: IND-E; LED_D10.0mm
LED5: IND-D; LED_D10.0mm
LED6: IND-C; LED_D10.0mm
LED7: IND-B; LED_D10.0mm
LED8: IND-A; LED_D10.0mm
R1, R2, R3, R4, R5, R6, R7, R8: 150; R_Axial_DIN0207_L6.3mm_D2.5mm_P10.16mm_Horizontal

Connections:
/DD.A01: J1.3, J2.4, J3.4
/DD.A10: J1.1, J2.2, J3.2
/DD.B01: J1.7, J2.8, J3.8
/DD.B10: J1.5, J2.6, J3.6
/DD.C01: J1.11, J2.12, J3.12
/DD.C10: J1.9, J2.10, J3.10
/DD.IND: J1.13, J2.14, J3.14
/SD.A: J2.3, J3.3, R8.1
/SD.B: J2.5, J3.5, R7.1
/SD.C: J2.7, J3.7, R6.1
/SD.D: J2.9, J3.9, R5.1
/SD.E: J2.11, J3.11, R4.1
/SD.F: J2.13, J3.13, R3.1
/SD.G: J2.15, J3.15, R2.1
/SD.P: J2.17, J3.17, R1.1
/SDA.A: LED8.1 (K), R8.2
/SDA.B: LED7.1 (K), R7.2
/SDA.C: LED6.1 (K), R6.2
/SDA.D: LED5.1 (K), R5.2
/SDA.E: LED4.1 (K), R4.2
/SDA.F: LED3.1 (K), R3.2
/SDA.G: LED2.1 (K), R2.2
/SDA.P: LED1.1 (K), R1.2
GND: GND1.1, J2.1, J2.18, J3.1, J3.18
unnamed: J1.2, J1.4, J1.6, J1.8, J1.10, J1.12, J1.14, LED1.2 (A), LED2.2 (A), LED3.2 (A), LED4.2 (A), LED5.2 (A), LED6.2 (A), LED7.2 (A), LED8.2 (A)
unnamed: J2.16, J3.16

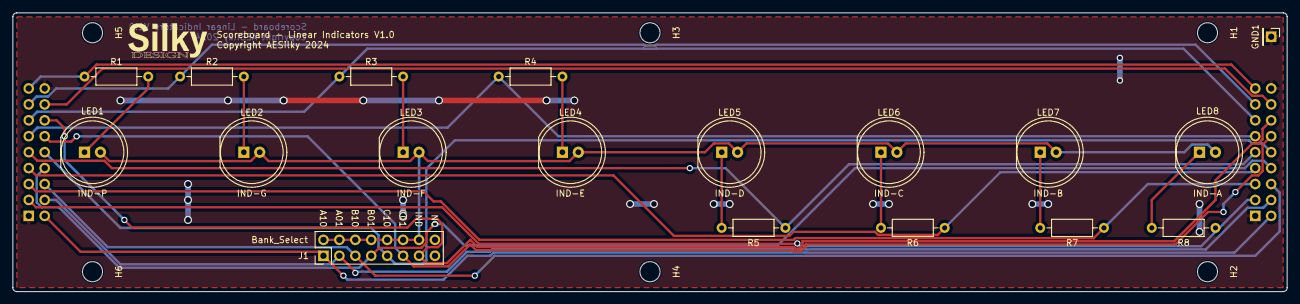
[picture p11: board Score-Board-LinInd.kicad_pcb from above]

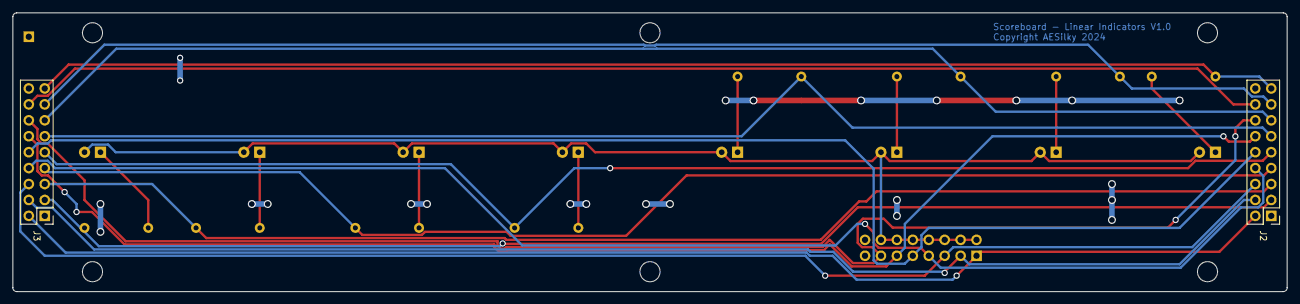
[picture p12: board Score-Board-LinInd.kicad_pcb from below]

Board: 2 copper layers, 203.2 x 44.5 mm, 27 parts (2 on the bottom side), 26 nets.

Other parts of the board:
G1: LOGO; SILKY-DESIGN-logo-0_50-AES

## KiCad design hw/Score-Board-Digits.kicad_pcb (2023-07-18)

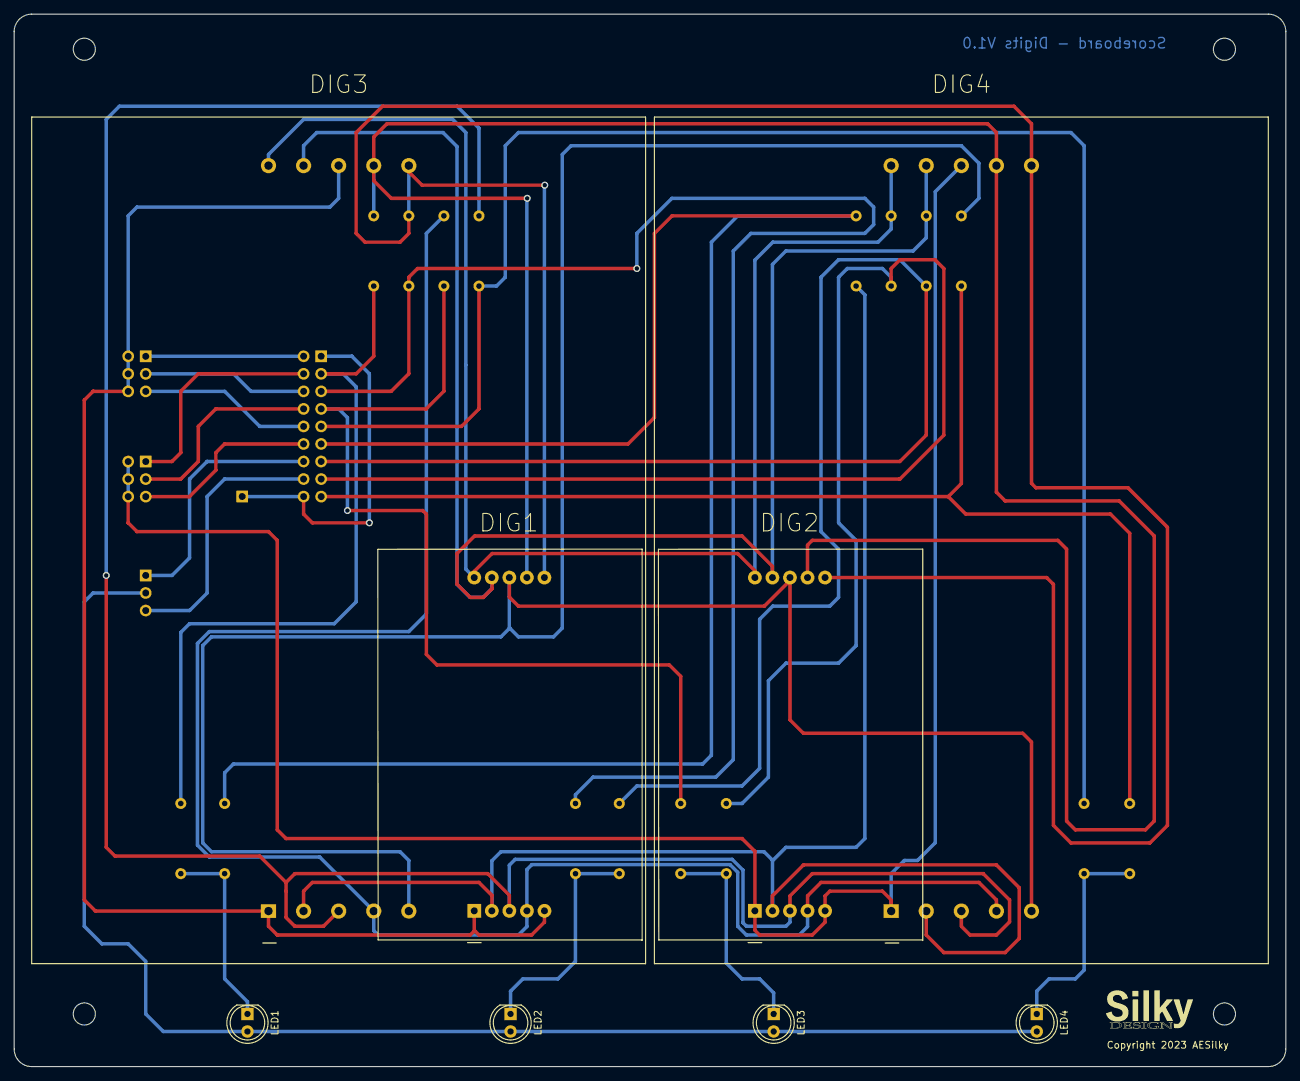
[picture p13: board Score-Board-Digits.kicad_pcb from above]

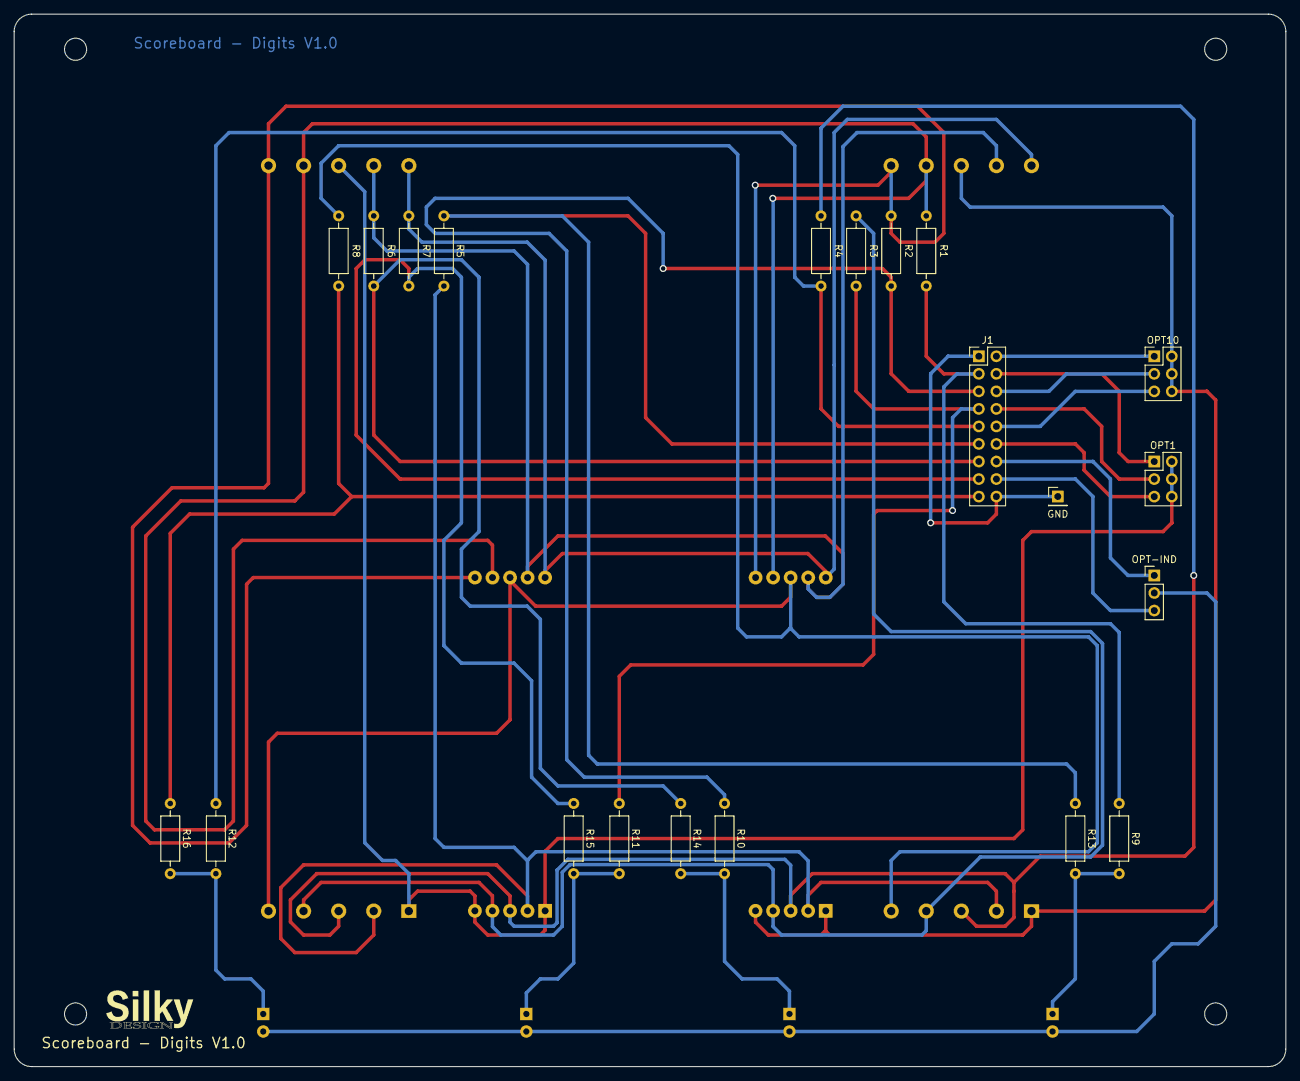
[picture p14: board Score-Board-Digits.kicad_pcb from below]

Board: 2 copper layers, 184.1 x 152.4 mm, 33 parts (21 on the bottom side), 32 nets.

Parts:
DIG1, DIG2: WJLEDS18012TUR11; DISP-CL18011BS-AES
DIG3, DIG4: WJLEDS40012TUR11; DISP-40101BCR-AES
GND: Conn_01x01; PinHeader_1x01_P2.54mm_Vertical
H1, H2, H3, H4: MountingHole; MountingHole_3.2mm_M3
J1: Conn_02x09_Odd_Even; PinHeader_2x09_P2.54mm_Vertical
LED1: IND-A1; LED_D5.0mm
LED2: IND-A2; LED_D5.0mm
LED3: IND-A3; LED_D5.0mm
LED4: IND-A4; LED_D5.0mm
OPT1, OPT10: Conn_02x03_Odd_Even; PinHeader_2x03_P2.54mm_Vertical
OPT-IND: Opt_1-2; PinHeader_1x03_P2.54mm_Vertical
R1, R2, R3, R4, R5, R6, R7: 77; R_Axial_DIN0207_L6.3mm_D2.5mm_P10.16mm_Horizontal
R8, R9, R10, R11, R12, R13, R14, R15, R16: 100; R_Axial_DIN0207_L6.3mm_D2.5mm_P10.16mm_Horizontal

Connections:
/SD.A: J1.3, R1.1, R9.1
/SD.B: J1.5, R2.1, R10.1
/SD.C: J1.7, R3.1, R11.1
/SD.D: J1.9, R4.1, R12.1
/SD.E: J1.11, R5.1, R13.1
/SD.F: J1.13, R6.1, R14.1
/SD.G: J1.15, R7.1, R15.1
/SD.P: J1.17, R8.1, R16.1
/SDA.A: DIG1.7 (A), DIG2.7 (A), DIG3.7 (A), DIG4.7 (A), R1.2
/SDA.B: DIG1.6 (B), DIG2.6 (B), DIG3.6 (B), DIG4.6 (B), R2.2
/SDA.C: DIG1.4 (C), DIG2.4 (C), DIG3.4 (C), DIG4.4 (C), R3.2
/SDA.D: DIG1.3 (D), DIG2.3 (D), DIG3.3 (D), DIG4.3 (D), R4.2
/SDA.E: DIG1.2 (E), DIG2.2 (E), DIG3.2 (E), DIG4.2 (E), R5.2
/SDA.F: DIG1.9 (F), DIG2.9 (F), DIG3.9 (F), DIG4.9 (F), R6.2
/SDA.G: DIG1.10 (G), DIG2.10 (G), DIG3.10 (G), DIG4.10 (G), R7.2
/SDA.P: DIG1.8 (DP), DIG2.8 (DP), DIG3.5 (DP), DIG4.5 (DP), R8.2
GND: GND.1, J1.1, J1.18
unnamed: J1.2, OPT10.1
unnamed: J1.4, OPT1.1
unnamed: J1.6, OPT10.3
unnamed: J1.8, OPT1.3
unnamed: J1.10, OPT10.5
unnamed: J1.12, OPT1.5
unnamed: J1.14, OPT-IND.1 (Pin_A)
unnamed: J1.16, OPT-IND.3 (Pin_B)
unnamed: LED1.2 (A), LED2.2 (A), LED3.2 (A), LED4.2 (A), OPT-IND.2 (Pin_Common)
unnamed: LED1.1 (K), R9.2, R13.2
unnamed: LED2.1 (K), R10.2, R14.2
unnamed: LED3.1 (K), R11.2, R15.2
unnamed: LED4.1 (K), R12.2, R16.2
unnamed: DIG2.1 (CA), DIG2.5 (CA), DIG4.1 (CA), DIG4.8 (CA), OPT1.2, OPT1.4, OPT1.6
unnamed: DIG1.1 (CA), DIG1.5 (CA), DIG3.1 (CA), DIG3.8 (CA), OPT10.2, OPT10.4, OPT10.6

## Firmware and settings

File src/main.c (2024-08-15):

/**
 * Scores main application.
 *
 * Copyright 2023 AESilky
 * SPDX-License-Identifier: MIT License
 *
*/
#include "pico/binary_info.h"
//
#include "system_defs.h" // Main system/board/application definitions
//
#include "board.h"
#include "debug_support.h"
//
#include "be/be.h"
#include "config/config.h"
#include "rc/rc.h"
#include "ui/ui.h"
//
#include "display/oled1106_spi/display_oled1106.h"

#define DOT_MS 60 // Dot at 20 WPM
#define UP_MS  DOT_MS
#define DASH_MS (2 * DOT_MS)
#define CHR_SP (3 * DOT_MS)

 // 'H' (....) 'I' (..)
static const int32_t say_hi[] = {
    DOT_MS,
    UP_MS,
    DOT_MS,
    UP_MS,
    DOT_MS,
    UP_MS,
    DOT_MS,
    CHR_SP,
    DOT_MS,
    UP_MS,
    DOT_MS,
    1000, // Pause before repeating
    0 };

int main()
{
    // useful information for picotool
    bi_decl(bi_program_description("OS and Control for AES Scoreboard"));

    // Board/base level initialization
    if (board_init() != 0) {
        panic("Board init failed.");
    }

    const config_sys_t* system_cfg = config_sys();

    // Indicate that we are awake
    if (debug_mode_enabled()) {
        tone_sound_duration(250);
    }
    int sc = sizeof(char);
    int ss = sizeof(short);
    int si = sizeof(int);
    int sl = sizeof(long);
    debug_printf(true, "Size of char: %d  short: %d  int: %d  long: %d\n", sc, ss, si, sl);
    // Uncomment to force starting in Debug Mode
    //debug_mode_enable(true);

    led_on_off(say_hi);

    sleep_ms(2000);
    //disp_font_test();

    // Set up the Backend (needs to be done before starting the UI)
    be_module_init();

    // Launch the UI (core-1 Message Dispatching Loop)
    start_ui();

    // Enable the IR receivers
    rc_enable_ir(system_cfg->ir1_is_rc, system_cfg->ir2_is_rc);

    // Launch the Backend (core-0 (endless) Message Dispatching Loop
    // (!!! THIS NEVER RETURNS !!!)
    start_be();

    // How did we get here?!
    error_printf(true, "scores - Somehow we are out of our endless message loop in `main()`!!!");
    disp_clear(true);
    disp_string(1, 0, "!!!!!!!!!!!!!!!!", false, true);
    disp_string(2, 0, "! OS LOOP EXIT !", false, true);
    disp_string(3, 0, "!!!!!!!!!!!!!!!!", false, true);
    // ZZZ Reboot!!!
    return 0;
}

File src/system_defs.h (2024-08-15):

#ifndef _SYSTEM_DEFS_H_
#define _SYSTEM_DEFS_H_
#ifdef __cplusplus
extern "C" {
#endif

#include "pico/stdlib.h"

#define scores_VERSION_INFO "Scores v0.1"  // ZZZ get from a central name/version string

/**
 * @brief Flag indicating that the board is a Pico-W
 */
#ifdef PICO_DEFAULT_LED_PIN
    #define BOARD_IS_PICO
#else
    #define BOARD_IS_PICOW
#endif


#undef putc     // Undefine so the standard macros will not be used
#undef putchar  // Undefine so the standard macros will not be used

#include "hardware/exception.h"
#include "hardware/pio.h"
#include "pico/multicore.h"
#include "pico/stdlib.h"

// SPI
//
// Scores uses SPI-1 for the SD Card
//
// The SPI GPIO pins are also used for segment enables for the 7 segment display.
// Therefore, the 7Seg displays can not be on while the SD card is being
// accessed. The shared GPIO pins must be configured for driving the segments when
// the display digits are going to be driven and configured for SPI when the SD
// card is going to be accessed (read or write)l
//
// Note: 'Pins' are the GPIO number, not the physical pins on the device.
//

// Using SPI 0 for the SD Card and Display
#define SPI_DISP_SDC_DEVICE spi0    // Hardware SPI to use
#define SPI_DISP_SDC_SCK     2      // DP-4
#define SPI_DISP_SDC_MOSI    3      // DP-5
#define SPI_DISP_SDC_MISO    4      // DP-6
#define SPI_DISP_CS          6      // DP-9
#define SPI_DISP_CD          7      // DP-10
#define SPI_SDC_CS           5      // DP-7

// Chip select values/levels
#define SPI_CS_ENABLE        0      // LOW
#define SPI_CS_DISABLE       1      // HIGH

// PIO Blocks
#define PIO_PANEL_DRIVE_BLOCK   pio0        // PIO Block 0 is used to drive the panel
#define PIO_PANEL_DRIVE_SM      0           // State Machine 0 is used for the panel
#define PIO_IR_BLOCK            pio1        // PIO Block 1 is used to read the IR ports
#define PIO_IR_IRQ              PIO1_IRQ_0  // PIO IRQ to use for the IR
#define PIO_IR_A_SM             0           // State Machine 0 is used to read the front IR (A)
#define PIO_IR_B_SM             1           // State Machine 1 is used to read the rear IR (B)

// Segment Enable
#define PANEL_DIGIT_SEG_A_GPIO    15      // DP-20
#define PANEL_DIGIT_SEG_B_GPIO    14      // DP-19
#define PANEL_DIGIT_SEG_C_GPIO    13      // DP-17
#define PANEL_DIGIT_SEG_D_GPIO    12      // DP-16
#define PANEL_DIGIT_SEG_E_GPIO    11      // DP-15
#define PANEL_DIGIT_SEG_F_GPIO    10      // DP-14
#define PANEL_DIGIT_SEG_G_GPIO     9      // DP-12
#define PANEL_DIGIT_SEG_P_GPIO     8      // DP-11 (Decimal Point)

// Indicator Enable (simply renamed segment enables)
#define PANEL_IND_TEAM_A_1        PANEL_DIGIT_SEG_A
#define PANEL_IND_TEAM_A_2        PANEL_DIGIT_SEG_B
#define PANEL_IND_TEAM_A_3        PANEL_DIGIT_SEG_C
#define PANEL_IND_TEAM_A_4        PANEL_DIGIT_SEG_D
#define PANEL_IND_TEAM_B_1        PANEL_DIGIT_SEG_E
#define PANEL_IND_TEAM_B_2        PANEL_DIGIT_SEG_F
#define PANEL_IND_TEAM_B_3        PANEL_DIGIT_SEG_G
#define PANEL_IND_TEAM_B_4        PANEL_DIGIT_SEG_P

#define PANEL_DIGIT_SEG_OFF      0
#define PANEL_DIGIT_SEG_ON       1

// Digit Enable
// The digits are:
//  A10,A01 (Team A)
//  B10,B01 (Team B)
//  C10,C01 (Period/Time)
//  Indicator (4 Leds under Team A, 4 Leds under Team B)
#define PANEL_DIGIT_A10_GPIO    16      // DP-21
#define PANEL_DIGIT_A01_GPIO    17      // DP-22
#define PANEL_DIGIT_B10_GPIO    18      // DP-24
#define PANEL_DIGIT_B01_GPIO    19      // DP-25
#define PANEL_DIGIT_C10_GPIO    20      // DP-26
#define PANEL_DIGIT_C01_GPIO    21      // DP-27
#define PANEL_DIGIT_IND_GPIO    22      // DP-29

#define PANEL_DIGIT_OFF          0
#define PANEL_DIGIT_ON           1

#define PANEL_PIO_GPIO_BASE     PANEL_DIGIT_SEG_P_GPIO
#define PANEL_PIO_GPIO_COUNT   15

// Other GPIO
#define IR_A_GPIO               27          // DP-32
#define IR_B_GPIO               28          // DP-33
#define TONE_DRIVE              26          // DP-31 - Buzzer drive
#define USER_INPUT_SW           IR_B_GPIO   // DP-33 - Shared with IR-B.
#define SW_BANK1_GPIO           27          // Boards are set up to use IR or Switch Banks
#define SW_BANK1_ADC            1           // Switch banks are read using the ADC
#define SW_BANK2_GPIO           28          // Boards are set up to use IR or Switch Banks
#define SW_BANK2_ADC            2           // Switch banks are read using the ADC

#define IRQ_INPUT_SW            IR_B_GPIO    // DP-33 - Shared with IR-B

// User Input Switch support
#define USER_SW_OPEN             1      // Switch is connected to GND
#define USER_SW_CLOSED           0

// Buzzer/Tone support
#define TONE_OFF 0
#define TONE_ON  1

// User input controls
#define SWITCH_LONGPRESS_DEFAULT 800 // 0.8 seconds (800ms) is considered a 'long press'
#define SWITCH_REPEAT_MS 250 // If a switch is long-pressed, repeat it every 1/4 second.

#ifdef __cplusplus
}
#endif
#endif // _SYSTEM_DEFS_H_

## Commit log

2023-06-14 Full schematic. ERC not passing yet.
    [Score-Board.kicad_pcb, Score-Board.kicad_sch]
2023-06-17 Schematic complete v0.1. Ready for layout.
    [Score-Board.kicad_sch]
2023-06-18 Schematic updated with 3 digit boards
    [Score-Board.kicad_sch, digits.kicad_sch]
2023-06-18 Schematic updated with digit drive resistors
    [Score-Board.kicad_sch, digits.kicad_sch]
2023-06-19 Footprints assigned
    [Score-Board.kicad_sch, digits.kicad_sch]
2023-06-19 Separate Main and Digits projects
    [Score-Board-Digits.kicad_pcb, Score-Board-Digits.kicad_sch, Score-Board.kicad_pcb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]
2023-06-20 Digits schmatic ready for layout
    [Score-Board-Digits.kicad_sch]
2023-06-20 Initial PCB component placement
    [Score-Board-Digits.kicad_pcb, Score-Board-Digits.kicad_sch]
2023-06-21 PCB routed v1
    [Score-Board-Digits.kicad_pcb]
2023-06-21 Main schematic ready for board layout
    [Score-Board-Digits.kicad_pcb, Score-Board-Digits.kicad_sch, Score-Board.kicad_sch]
2023-07-01 PCB routing done
    [Score-Board-Digits.kicad_pcb, Score-Board-Digits.kicad_sch, Score-Board.kicad_pcb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]
2023-07-03 Initial source code
    [mukob.sample.cfg, mukob.sys.sample.cfg]
2023-07-18 Add pull-down res to segment drives.
    [Score-Board-Digits-B_Cu.gbr, Score-Board-Digits-B_Mask.gbr, Score-Board-Digits-B_Paste.gbr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]
2023-07-22 SPI for display & SD, Seg&Dig enables 16 straight GPIOs.
    [Score-Board.kicad_pcb, Score-Board.kicad_sch]
2023-07-22 Add board cutout for Wi-Fi ant area of Pico-W.
    [Score-Board.kicad_pcb]
2023-08-06 v1.0 Board
    [Score-Board-B_Cu.gbr, Score-Board-B_Mask.gbr, Score-Board-B_Paste.gbr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]
2024-07-22 Linear Style: Panel and Switches boards.
    [Score-Board-LinInd-B_Cu.gbr, Score-Board-LinInd-B_Mask.gbr, Score-Board-LinInd-B_Paste.gbr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]
2024-07-23 Scorekeeper with Numeric and Linear panels. (plus repair)
    [mukob.sample.cfg, mukob.sys.sample.cfg, sample.sys.cfg]
2024-08-24 BOM generated.
    [Score-Board.kicad_pcb]

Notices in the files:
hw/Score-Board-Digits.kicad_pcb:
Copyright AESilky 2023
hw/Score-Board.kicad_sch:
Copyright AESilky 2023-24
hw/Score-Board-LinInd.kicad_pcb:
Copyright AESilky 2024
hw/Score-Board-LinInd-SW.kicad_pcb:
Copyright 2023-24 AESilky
